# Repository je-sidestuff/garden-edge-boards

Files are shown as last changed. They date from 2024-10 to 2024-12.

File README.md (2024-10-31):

# garden-edge-boards
A self-contained OpenSCAD repository with a framework for arranging garden edge boards, such as for raised beds.

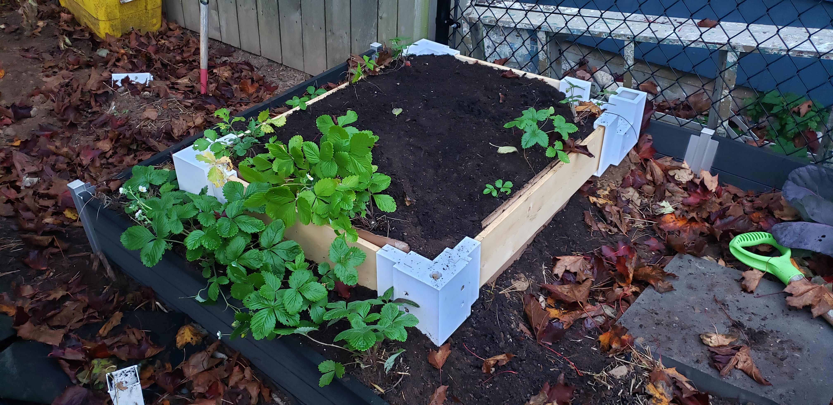
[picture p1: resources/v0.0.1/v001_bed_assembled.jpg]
Assembled Image


## Core Components
The main elements in the framework are the board holder, the tongue and groove attachments for board holders, and the posts.

### Board Holder
The board holder is a press-fitting sheath for a board that can be used to connect to an assembly. The original board holder has a connector backing with a tongue that can be connected with dowels.

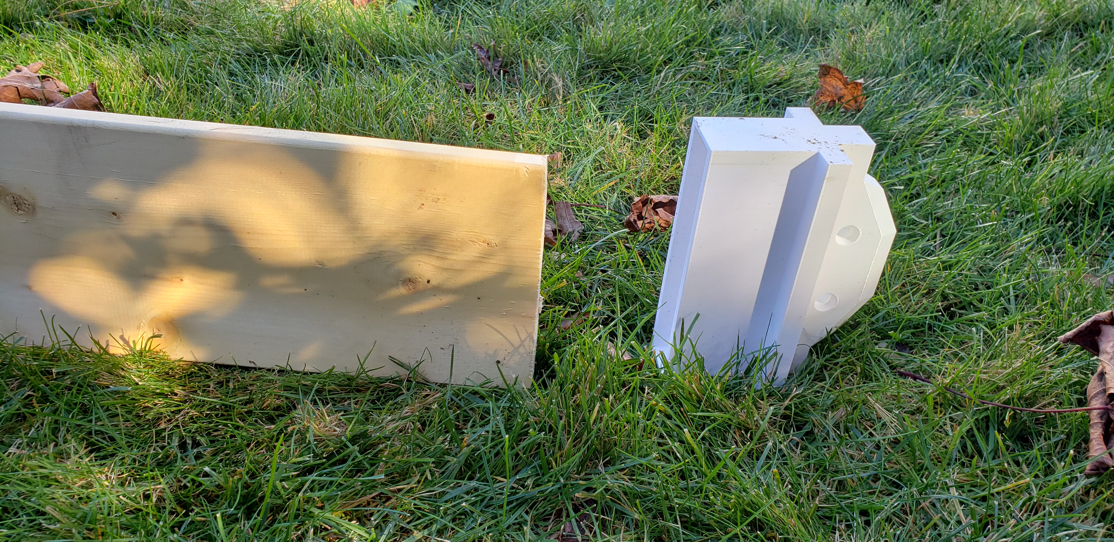
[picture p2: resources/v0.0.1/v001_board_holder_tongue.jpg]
Board Holder With Tongue


### Tongue and Groove
The tonque and groove mating system connect using dowels and form a stable assembly. Normally the groove will be embedded in a post or a similar structure.

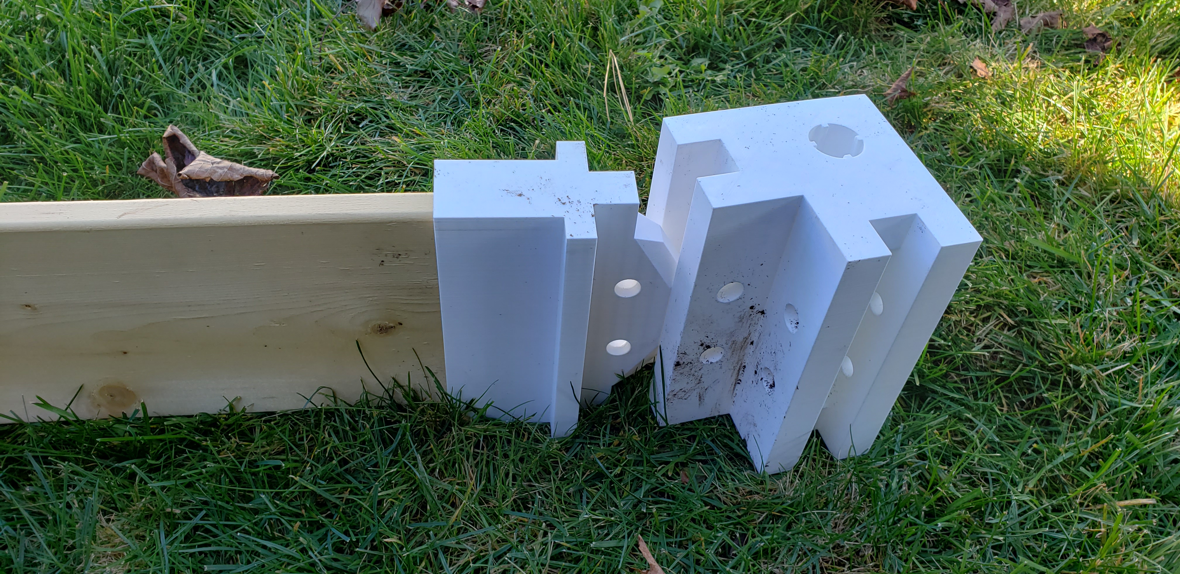
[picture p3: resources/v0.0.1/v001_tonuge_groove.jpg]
Tongue And Groove


### Post Assemblies
Post assemblies contain one or more grooves as well as a central connector conduit that may be used to fasten them to the ground. In the initial iteration these grooves must be separated by 90 degree angles. The post assemblies may be encased in shells to keep the internal connections clean.

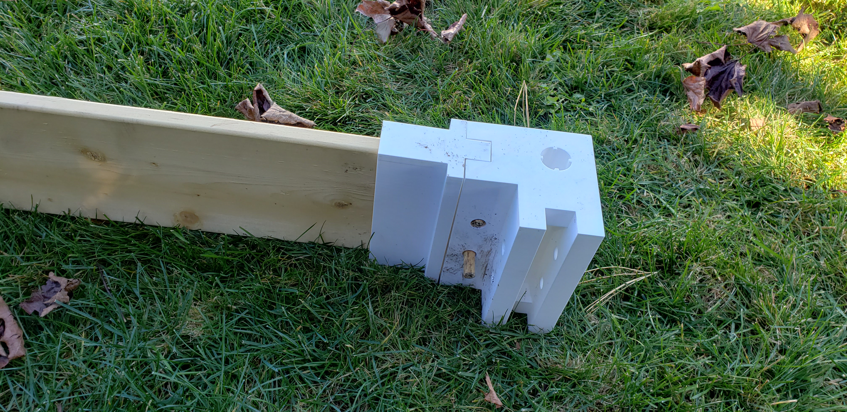
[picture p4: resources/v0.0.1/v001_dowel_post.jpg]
Post Assembly


## Released Iterations

### v0.0.1 (Initial)
The [initial iteration](./docs/v0.0.1.md) of the garden-edge-boards introduces the base components necessary to build a simple right-angles raised bed using 1-by-6s.

The initial iteration is undergoing [testing](./docs/strawberry_test_bed.md) in a simple square configuration in USDA hardiness zone 6B.

## Planned Iterations

### v0.0.2
The second iteration will be used to fix any issues arising during testing of v0.0.1, and will add a small set of features.

Features include:
- Non-right-angle connections for posts
- Multiple board size configuration presets
- Mating components for connector conduits
- Support for stacking multiple layers

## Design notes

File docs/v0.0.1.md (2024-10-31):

# v0.0.1

This initial release provides the necessary components for a minimum viable product style test. The release coincides with the creation of the v0.0.1 [strawberry test bed](./strawberry_test_bed.md) lower tier. This long-term test will have periodic updates made with details on results.

The following components are included in this release:
 - Board Holder Tongue
 - Right-angle Grooved Post
 - Simple Outer Shell

## Board Holder Tongue

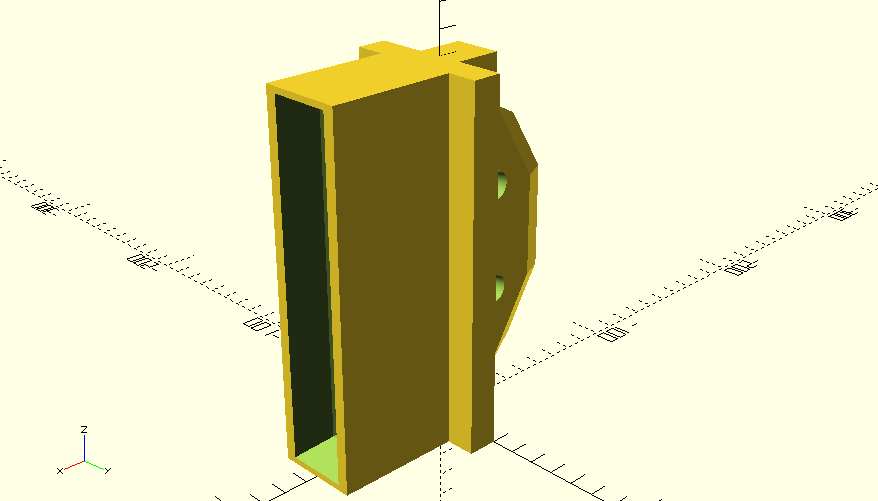
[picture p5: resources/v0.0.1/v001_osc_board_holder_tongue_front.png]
Tongue Front


The board holder tongue is the element that press-fits onto the end of a board and then mates with a grooved component.

The board-side connector has a narrowing mouth to improve board insertion, and the tongue-side is fastened into the groove using dowels inserted laterally through the tongue and groove.

## Grooved Post

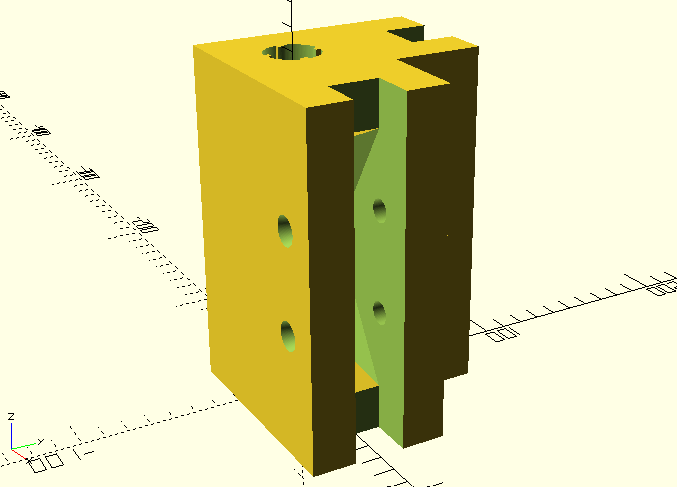
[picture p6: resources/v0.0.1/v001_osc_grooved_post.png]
Grooved Post


The grooved post accepts and secures tongued board holders and allows itself to be fastened to the ground via a rod placed through its connector conduit.

The conduit where the stake is inserted tapers to a larger opening on the top and bottom. The mouth on each of the top and bottom surfaces have mating teeth that may be used for capping the stake without a shell, stacking multiple layers of grooved posts, and/or affixing additional components.

The grooves each have lateral holes to allow insertion of dowels to fasten the tongues in place.

## Assembly Shell

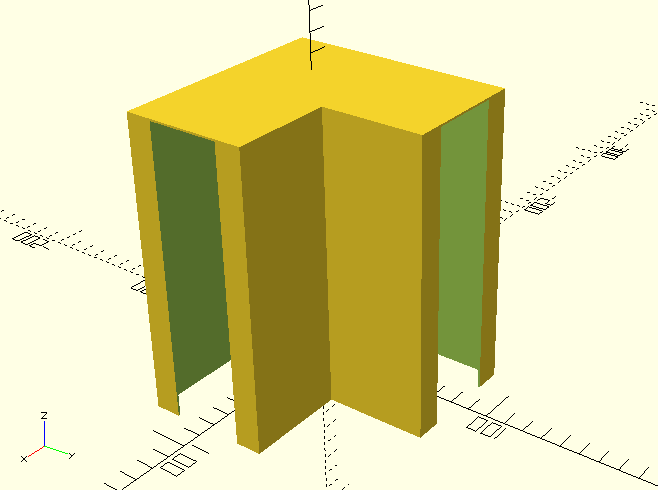
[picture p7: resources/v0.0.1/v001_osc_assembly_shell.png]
Assembly Shell


The assembly shell is a simple outer covering that may be placed over the posts and board holders once the components are connected. It keeps dust and debris out of the connection mechanisms and reduces the amount of water that enters the system.

## Notes

So far this model is provided for-but-not-with mating components via the connector conduit.

A blender file (resources/v0.0.1/1by6BoardEdge.blend) is included as a reference. This file contains an experimental model used to perform some size tests before the OpenSCAD content was created. It also contains some miscellaneous models used for inspection and comparison.

## Known Items to Address

This iteration contains a few areas with known paths to improvement:

General Size Selection -
The sizes of all components was done in a quick, easy, safe way. Sizes may be further optimized to reduce the amount of material needed.

Size Presets -
This iteration has all values defined to work with 1-by-6 boards and 3/8" dowels. Additional size presets may be added.

Dowel Coupling Mechanisms Require Push -
Currently removing the pin-dowels requires the user to push them through with another dowel or object. A feature allowing them to be pulled out with plier or similar would allow the mechanisms to be kept cleaner.

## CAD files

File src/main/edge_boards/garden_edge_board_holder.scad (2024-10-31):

//////////////////////////////////////////////////////////////////////
//
// Filename: garden_edge_board_holder.scad
//   The garden edge board holder joins multiple boards together at an edge post.
//   The edge may be anchored to the ground with rebar or a dowel.
// Author:
//   Jordan Edsall
// Date:
//   2024-09-18
// License:
//   https://opensource.org/licenses/MIT
// 
//////////////////////////////////////////////////////////////////////

// Variables
STD_FN = 128;
SMALL_VAL = 0.0000000000000001;
BIG_VAL = 10000;

geb_mating_gap = 0.975;

// Non-printed component variables
1_by_6_width = 15;
1_by_6_height = 134;

geb_board_width = 1_by_6_width;
geb_board_width_gap = 0.625;
geb_board_height = 1_by_6_height;
geb_board_height_gap = 0.9375;

3_8th_inch_dowel_radius = 4.7625;

geb_mate_dowel_radius = 3_8th_inch_dowel_radius;
geb_mate_dowel_gap = 0.225;

// Structure Variables
geb_holder_hollow_delta = 10;
geb_holder_width = geb_board_width + 20;
geb_holder_height = geb_board_height + 16;
geb_holder_transition_board_depth = 15;
geb_holder_flat_board_depth = 45;
geb_holder_board_backing_depth = 5;
geb_holder_post_backing_width = 60;
geb_holder_post_backing_depth = 12.5;
geb_holder_body_depth = geb_holder_transition_board_depth + geb_holder_flat_board_depth + geb_holder_board_backing_depth;
geb_holder_wall_thickness = 1;

// Tongue Variables
geb_tongue_start_depth = 20;
geb_tongue_front_depth = 50;
geb_tongue_back_depth = 40;
geb_tongue_start_width = geb_holder_post_backing_width * 0.45;
geb_tongue_front_width = geb_holder_post_backing_width * 0.2;
geb_tongue_back_width = geb_holder_post_backing_width * 0.35;
geb_tongue_start_height = 20;
geb_tongue_back_height = geb_holder_height - 2*geb_tongue_start_height;
geb_tongue_front_height = geb_tongue_back_height * 0.4;

// Groove Variables
geb_groove_connector_depth = geb_tongue_front_depth + 5;
geb_groove_start_depth = geb_tongue_start_depth;
geb_groove_front_depth = geb_tongue_back_depth;
geb_groove_back_depth = geb_tongue_front_depth;
geb_groove_front_width = geb_tongue_back_width;
geb_groove_back_width = geb_tongue_front_width;
geb_groove_front_height = geb_tongue_back_height;
geb_groove_back_height = geb_tongue_front_height;

// Post Variables
geb_connector_toptube_inner_radius = 12;
geb_connector_toptube_depth = 15;
geb_connector_midtube_inner_radius = 8;
geb_connector_transition_depth = 15;
geb_connector_offset = 15;
geb_connector_tooth_intrusion = (geb_connector_toptube_inner_radius - geb_connector_midtube_inner_radius) * 0.4;
geb_connector_tooth_width = 4;

// Shell Variables
geb_shell_wall_thickness = 1;



// Board Holder Modules

// Module: geb_board_holder_body()
// Description:
//   Creates a volume where a board can be inserted standing vertically with a backing of equal or greater width.
//   The [0, 0, 0] point is at the bottom of the volume, with all geometry in the +X region, and the front facing in the +X direction.
// Arguments:
//   bh_body_depth         - The depth of the board holder body, including the post backing.
//   bh_width              - The width of the board holder portion of the board holder body.
//   bh_height             - The height of the board holder body and post backing (+Z). 
//   bh_trans_hollow_depth - The depth of the transition section of the hollow the board sits in.
//   bh_flat_hollow_depth  - The depth of the flat back section of the hollow the board sits in.
//   bh_hollow_width       - The width of the flat back section of hollow where the board sits.
//   bh_hollow_height      - The height of the flat back section of hollow where the board sits.
//   bh_hollow_delta       - The difference in hollow width and height of the front and back.
//   bh_post_backing_depth - The depth of the body section that butts up against another object.
//   bh_post_backing_width - The width of the body section that butts up against another object.
module geb_board_holder_body(
        bh_body_depth = geb_holder_body_depth,
        bh_width = geb_holder_width,
        bh_height = geb_holder_height,
        bh_trans_hollow_depth = geb_holder_transition_board_depth,
        bh_flat_hollow_depth = geb_holder_flat_board_depth,
        bh_hollow_width = geb_board_width + geb_board_width_gap,
        bh_hollow_height = geb_board_height + geb_board_height_gap,
        bh_hollow_delta = geb_holder_hollow_delta,
        bh_post_backing_depth = geb_holder_post_backing_depth,
        bh_post_backing_width = geb_holder_post_backing_width
        ) {
            
    bh_full_hollow_depth = bh_trans_hollow_depth + bh_flat_hollow_depth;
    
    // The board holder volume
    translate([bh_body_depth/2, 0, bh_height/2]) {
        difference() {
            
            translate([0,0,0]) {
                cube([bh_body_depth, bh_width, bh_height], center = true);
                translate([(bh_post_backing_depth - bh_body_depth)/2,0,0])
                    cube([bh_post_backing_depth, bh_post_backing_width, bh_height], center = true);
            }
            
            translate([bh_body_depth/2,0,0]) {
                cube([bh_full_hollow_depth*2, bh_hollow_width, bh_hollow_height], center = true);

                hull() {
                    cube([bh_trans_hollow_depth*2, bh_hollow_width, bh_hollow_height], center = true);
                    cube([SMALL_VAL, bh_hollow_width + bh_hollow_delta, bh_hollow_height + bh_hollow_delta], center = true);
                }
            }
        }
    }
}

// Module: geb_board_holder_tongue_positive() 
// Description:
//   Creates a tongue which stands vertically, pointing in the -X direction, meant to mate with a groove. The tongue has a flat section at the back and a tapered section at the front.
//   This module is the positive volume without any joining holes subtracted.
//   The [0, 0, 0] point is at the bottom of the volume, with all geometry in the -X region, and the front facing in the -X direction.
// Arguments:
//   btp_height              - The height of the board holder body and post backing (+Z).
//   btp_tongue_start_depth  - The depth at which the flat section stops and the tapered section begins.
//   btp_tongue_back_depth   - The maximum depth of the outsides of the tapered section.
//   btp_tongue_front_depth  - The maximum depth of the inside of the tapered section.
//   btp_tongue_back_width   - The width of the flat section and outside of the tapered section.
//   btp_tongue_front_width  - The width of the tapered ridge in the middle of the tongue in the Y dimension.
//   btp_tongue_back_height  - The maximum Z dimension of the tapered section.
//   btp_tongue_front_height - The Z dimension of the front of the tapered section.
module geb_board_holder_tongue_positive(
        btp_height = geb_holder_height,
        btp_tongue_start_depth = geb_tongue_start_depth,
        btp_tongue_back_depth = geb_tongue_back_depth,
        btp_tongue_front_depth = geb_tongue_front_depth,
        btp_tongue_back_width = geb_tongue_back_width,
        btp_tongue_front_width = geb_tongue_front_width,
        btp_tongue_back_height = geb_tongue_back_height,
        btp_tongue_front_height = geb_tongue_front_height
        ) {

    btp_delta_depth = btp_tongue_front_depth - btp_tongue_back_depth;
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

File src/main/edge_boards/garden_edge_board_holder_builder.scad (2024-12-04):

//////////////////////////////////////////////////////////////////////
//
// Filename: garden_edge_board_holder_builder.scad
//   The garden edge board holder joins multiple boards together at an edge post.
//   The post may be anchored to the ground with rebar or a dowel through a conduit.
//   The _lib.scad provides the methods needed to create the assemblies.
// Author:
//   Jordan Edsall
// Date:
//   2024-09-18
// License:
//   https://opensource.org/licenses/MIT
//
//////////////////////////////////////////////////////////////////////

include <garden_edge_board_holder_lib.scad>
include <garden_edge_board_holder_presets.scad>

// Variables

/*[Select Component to Build]*/
// This value selects the component to build.
geb_component_to_build = "Board Holder Tongue"; //["Board Holder Tongue", "Post with Grooves", "Assembly Shell"]

/*[Select Built-in Preset]*/
// This value selects from the options for fully defined configs.
geb_builtin_preset = "v_001_1_by_6"; //["v_001_1_by_6", "v_001_1_by_6_planner", "v_001_1_by_6_tiny_planner"]

echo("Building")
echo(geb_component_to_build)
echo("with preset")
echo(geb_builtin_preset)

if (geb_component_to_build == "Board Holder Tongue") {
    if (geb_builtin_preset == "v_001_1_by_6") {
        gebp_v0011b6_board_holder();
    }
    if (geb_builtin_preset == "v_001_1_by_6_planner") {
        gebp_v0011b6pln_board_holder();
    }
    if (geb_builtin_preset == "v_001_1_by_6_tiny_planner") {
        gebp_v0011b6tpln_board_holder();
    }
}
if (geb_component_to_build == "Post with Grooves") {
    if (geb_builtin_preset == "v_001_1_by_6") {
        gebp_v0011b6_board_holder_simple_post();
    }
    if (geb_builtin_preset == "v_001_1_by_6_planner") {
        gebp_v0011b6pln_board_holder_simple_post();
    }
    if (geb_builtin_preset == "v_001_1_by_6_tiny_planner") {
        gebp_v0011b6tpln_board_holder_simple_post();
    }
}
if (geb_component_to_build == "Assembly Shell") {
    if (geb_builtin_preset == "v_001_1_by_6") {
        gebp_v0011b6_board_holder_post_shell();
    }
    if (geb_builtin_preset == "v_001_1_by_6_planner") {
        gebp_v0011b6pln_board_holder_post_shell();
    }
    if (geb_builtin_preset == "v_001_1_by_6_tiny_planner") {
        gebp_v0011b6tpln_board_holder_post_shell();
    }
}

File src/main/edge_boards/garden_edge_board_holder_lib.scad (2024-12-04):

//////////////////////////////////////////////////////////////////////
//
// Filename: garden_edge_board_holder_lib.scad
//   The garden edge board holder joins multiple boards together at an edge post.
//   The post may be anchored to the ground with rebar or a dowel through a conduit.
//   The _lib.scad provides the methods needed to create the assemblies.
// Author:
//   Jordan Edsall
// Date:
//   2024-09-18
// License:
//   https://opensource.org/licenses/MIT
//
//////////////////////////////////////////////////////////////////////

// Variables
STD_FN = 128;
SMALL_VAL = 0.0000000000000001;
BIG_VAL = 10000;

geb_mating_gap = 0.975;

// Non-printed component variables
1_by_6_width = 15;
1_by_6_height = 134;

geb_board_width = 1_by_6_width;
geb_board_width_gap = 0.625;
geb_board_height = 1_by_6_height;
geb_board_height_gap = 0.9375;

3_8th_inch_dowel_radius = 4.7625;

geb_mate_dowel_radius = 3_8th_inch_dowel_radius;
geb_mate_dowel_gap = 0.225;

// Structure Variables
geb_holder_hollow_delta = 10;
geb_holder_width = geb_board_width + 20;
geb_holder_height = geb_board_height + 16;
geb_holder_transition_board_depth = 15;
geb_holder_flat_board_depth = 45;
geb_holder_board_backing_depth = 5;
geb_holder_post_backing_width = 60;
geb_holder_post_backing_depth = 12.5;
geb_holder_body_depth = geb_holder_transition_board_depth + geb_holder_flat_board_depth + geb_holder_board_backing_depth;
geb_holder_wall_thickness = 1;

// Tongue Variables
geb_tongue_start_depth = 20;
geb_tongue_front_depth = 50;
geb_tongue_back_depth = 40;
geb_tongue_start_width = geb_holder_post_backing_width * 0.45;
geb_tongue_front_width = geb_holder_post_backing_width * 0.2;
geb_tongue_back_width = geb_holder_post_backing_width * 0.35;
geb_tongue_start_height = geb_tongue_start_depth;
geb_tongue_back_height = geb_holder_height - 2*geb_tongue_start_height;
geb_tongue_front_height = geb_tongue_back_height * 0.4;

// Groove Variables
geb_groove_connector_depth = geb_tongue_front_depth + 5;
geb_groove_start_depth = geb_tongue_start_depth;
geb_groove_front_depth = geb_tongue_back_depth;
geb_groove_back_depth = geb_tongue_front_depth;
geb_groove_front_width = geb_tongue_back_width;
geb_groove_back_width = geb_tongue_front_width;
geb_groove_front_height = geb_tongue_back_height;
geb_groove_back_height = geb_tongue_front_height;

// Post Variables
geb_post_fill_strategy = "braced"; // Allowed values are 'filled', 'hollow', and 'braced'
geb_post_fill_brace_thickness = 0.15;

geb_connector_toptube_inner_radius = 12;
geb_connector_toptube_depth = 15;
geb_connector_midtube_inner_radius = 8;
geb_connector_transition_depth = 15;
geb_connector_offset = 15;
geb_connector_tooth_intrusion = (geb_connector_toptube_inner_radius - geb_connector_midtube_inner_radius) * 0.4;
geb_connector_tooth_width = 4;

// Shell Variables
geb_shell_wall_thickness = 1;



// Board Holder Modules

// Module: geb_board_holder_body()
// Description:
//   Creates a volume where a board can be inserted standing vertically with a backing of equal or greater width.
//   The [0, 0, 0] point is at the bottom of the volume, with all geometry in the +X region, and the front facing in the +X direction.
// Arguments:
//   bhb_body_depth         - The depth of the board holder body, including the post backing.
//   bhb_width              - The width of the board holder portion of the board holder body.
//   bhb_height             - The height of the board holder body and post backing (+Z). 
//   bhb_trans_hollow_depth - The depth of the transition section of the hollow the board sits in.
//   bhb_flat_hollow_depth  - The depth of the flat back section of the hollow the board sits in.
//   bhb_hollow_width       - The width of the flat back section of hollow where the board sits.
//   bhb_hollow_height      - The height of the flat back section of hollow where the board sits.
//   bhb_hollow_delta       - The difference in hollow width and height of the front and back.
//   bhb_post_backing_depth - The depth of the body section that butts up against another object.
//   bhb_post_backing_width - The width of the body section that butts up against another object.
module geb_board_holder_body(
        bhb_body_depth = geb_holder_body_depth,
        bhb_width = geb_holder_width,
        bhb_height = geb_holder_height,
        bhb_trans_hollow_depth = geb_holder_transition_board_depth,
        bhb_flat_hollow_depth = geb_holder_flat_board_depth,
        bhb_hollow_width = geb_board_width + geb_board_width_gap,
        bhb_hollow_height = geb_board_height + geb_board_height_gap,
        bhb_hollow_delta = geb_holder_hollow_delta,
        bhb_post_backing_depth = geb_holder_post_backing_depth,
        bhb_post_backing_width = geb_holder_post_backing_width
        ) {
            
    bhb_full_hollow_depth = bhb_trans_hollow_depth + bhb_flat_hollow_depth;
    
    // The board holder volume
    translate([bhb_body_depth/2, 0, bhb_height/2]) {
        difference() {
            
            translate([0,0,0]) {
                cube([bhb_body_depth, bhb_width, bhb_height], center = true);
                translate([(bhb_post_backing_depth - bhb_body_depth)/2,0,0])
                    cube([bhb_post_backing_depth, bhb_post_backing_width, bhb_height], center = true);
            }
            
            translate([bhb_body_depth/2,0,0]) {
                cube([bhb_full_hollow_depth*2, bhb_hollow_width, bhb_hollow_height], center = true);

                hull() {
                    cube([bhb_trans_hollow_depth*2, bhb_hollow_width, bhb_hollow_height], center = true);
                    cube([SMALL_VAL, bhb_hollow_width + bhb_hollow_delta, bhb_hollow_height + bhb_hollow_delta], center = true);
                }
            }
        }
    }
}

// Module: geb_board_holder_tongue_positive() 
// Description:
//   Creates a tongue which stands vertically, pointing in the -X direction, meant to mate with a groove. The tongue has a flat section at the back and a tapered section at the front.
//   This module is the positive volume without any joining holes subtracted.
//   The [0, 0, 0] point is at the bottom of the volume, with all geometry in the -X region, and the front facing in the -X direction.
// Arguments:
//   btp_height              - The height of the board holder body and post backing (+Z).
//   btp_tongue_start_depth  - The depth at which the flat section stops and the tapered section begins.
//   btp_tongue_back_depth   - The maximum depth of the outsides of the tapered section.
//   btp_tongue_front_depth  - The maximum depth of the inside of the tapered section.
//   btp_tongue_back_width   - The width of the flat section and outside of the tapered section.
//   btp_tongue_front_width  - The width of the tapered ridge in the middle of the tongue in the Y dimension.
//   btp_tongue_back_height  - The maximum Z dimension of the tapered section.
//   btp_tongue_front_height - The Z dimension of the front of the tapered section.
module geb_board_holder_tongue_positive(
        btp_height = geb_holder_height,
        btp_tongue_start_depth = geb_tongue_start_depth,
        btp_tongue_back_depth = geb_tongue_back_depth,
        btp_tongue_front_depth = geb_tongue_front_depth,
        btp_tongue_back_width = geb_tongue_back_width,
        btp_tongue_front_width = geb_tongue_front_width,
        btp_tongue_back_height = geb_tongue_back_height,
        btp_tongue_front_height = geb_tongue_front_height
        ) {

    btp_delta_depth = btp_tongue_front_depth - btp_tongue_back_depth;
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

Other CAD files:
src/main/edge_boards/garden_edge_board_holder_presets.scad
resources/v0.0.1/1by6BoardEdge.blend

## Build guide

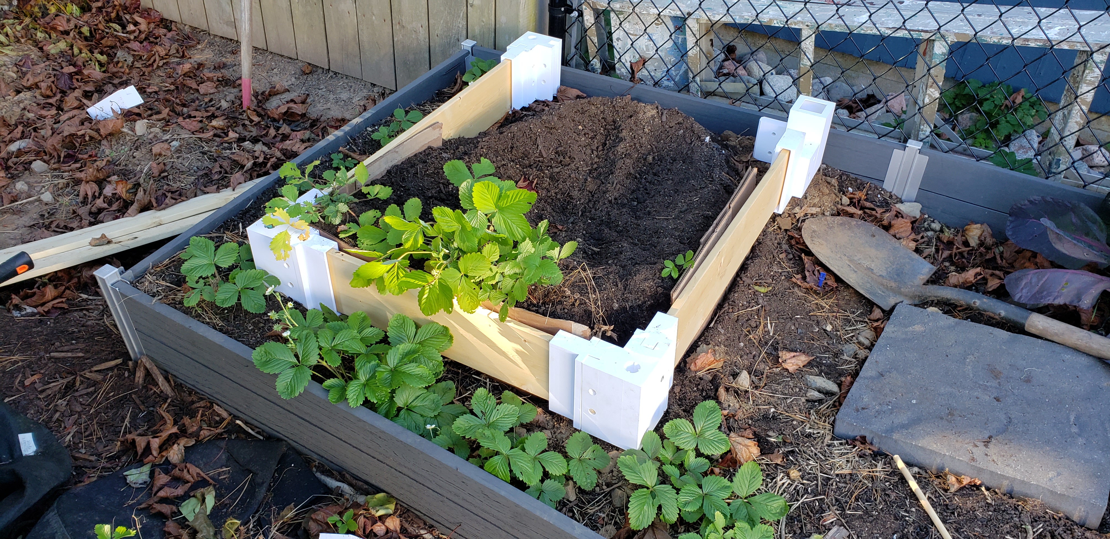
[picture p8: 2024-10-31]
resources/v0.0.1/v001_bed_nearly_assembled.jpg

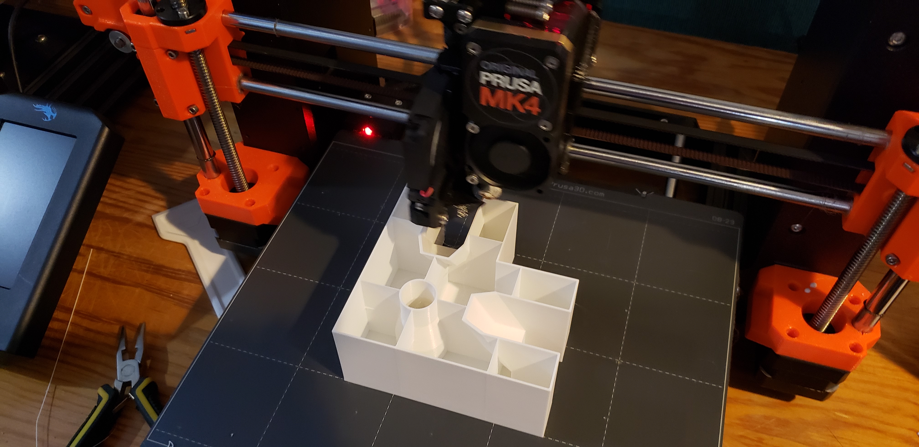
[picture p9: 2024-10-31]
resources/v0.0.1/v001_printing_braced_fill_strategy.jpg

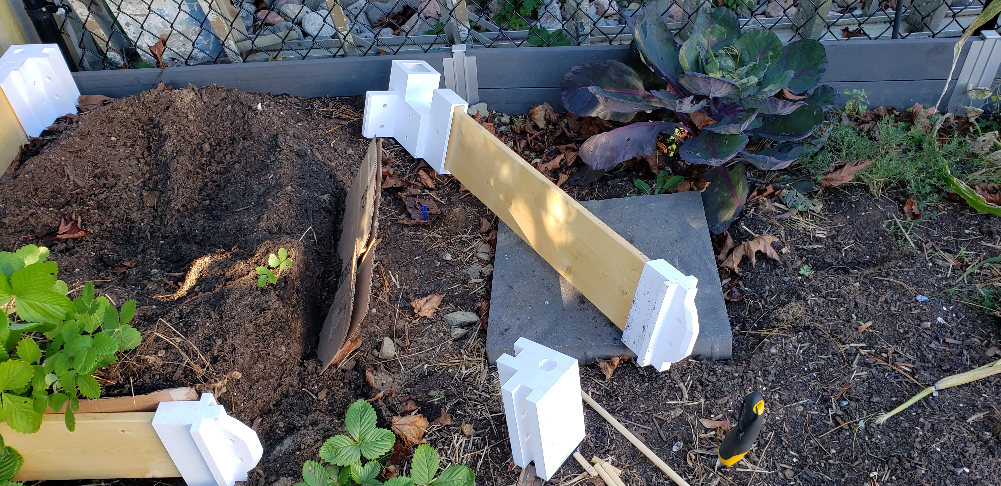
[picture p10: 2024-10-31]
resources/v0.0.1/v001_bed_partially_assembled.jpg

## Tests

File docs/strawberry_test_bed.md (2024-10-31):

# strawberry-test-bed

The strawberry test bed is a multi-tier stepped pyramid of strawberries, with the top two tiers build from the garden-edge-boards. The v0.0.1 lower tier was put in place on Oct 24th, 2024.

Assembled Image
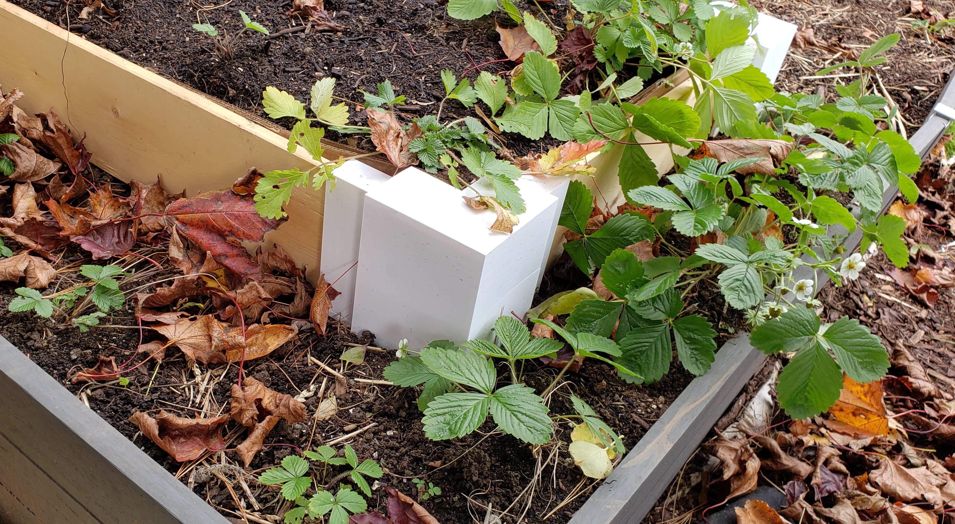
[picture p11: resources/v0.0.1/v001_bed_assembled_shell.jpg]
Assembled Image


## v0.0.1 Lower Tier Setup

The lower tier is created using the v0.0.1 size defaults. One post is created from the original blender experimental model and the remaining three are created from the v0.0.1 source. The components are all printed on a Prusa Mk4 with default configurations, using Hatchbox White PLA. All models are sliced with PrusaSlicer using a default Mk4 configuration and 0.15mm quality presets.

Several other attributes are varied between corners:
- Shells are present on two of the three corners under test
- Two of the three corners are hollow fill strategy and the other is braced fill strategy
- Two of the corners are fastened with rebar, one is fastened with a dowel

## Concerns / Items to watch for
- Water ingress in the corners without shells may cause issues with freezing
- The 1 by 6 boards are untreated and should be checked for degredation
- Some of side walls are backed with cardboard and others are not, so the impact on lifespan of the boards may be observed

## v0.0.1 Lower Tier Updates

Oct 24th, Initial Setup -
- Overall setup went smoothly with all parts fitting on first attempt
- Boards fit very tightly on Z axis, this may be a concern for splitting with freezing

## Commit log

2024-10-30 feat: First draft of tongued board holders, grooved posts, and assembly shell. Initial docs and documentation of original test setup.
    [1by6BoardEdge.blend, garden_edge_board_holder.scad]
2024-12-04 feat: Moved module into a _lib file, added presets and a builder. Also corrected minor issues including a non-manifold error with braced fill strategy.
    [garden_edge_board_holder_builder.scad, garden_edge_board_holder_lib.scad, garden_edge_board_holder_presets.scad]
